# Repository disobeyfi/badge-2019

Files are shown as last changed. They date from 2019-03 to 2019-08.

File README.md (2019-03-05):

# Disobey 2019 badge

Disobey 2019 badge is 3rd electronic badge produced for Disobey. Badge mainly serves as part of the puzzle at the event, while it also offers easy to learn embedded programming platform.

## Intro
Introduction to the badge is well covered here: https://wiki.badge.team/Disobey2019Badge/API

## Programming
Apps for the badge can be written in Micropython and released in https://badge.disobey.fi

The ESP32 firmware development (by badge.team) continues in https://github.com/badgeteam/micropython-esp32

## Features
* 6 RGB leds
* 6 touch buttons
* LCD screen with backlight
* piezoelectric buzzer
* WiFi (2.4 GHz)
* I2C bus
* serial via USB

## Team
* Heikki Juva - Management and hardware
* Kliment - Hardware, drivers and manufacturing
* Renze - Software
* Valtteri Raila - Puzzle
* Gaja - Software
* Otto - Graphics
* Teemu Hakala - Badge assembly workshops

## Thanks
* NotMyNick - The Father of Disobey
* badge.team for creating awesome platform for badges
* Helsinki Hacklab for providing the lab and tools for the workshops

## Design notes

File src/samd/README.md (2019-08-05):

# What is this?
This is the firmware running on the SAMD co-processor found on the Disobey 2019 badge

# How do I compile this firmware?
First install version 1.6.18 of the "Arduino SAMD boards" board support package using the Arduino boards manager.
Then navigate to ~/.arduino15/packages/arduino/hardware/samd and replace the 1.6.18 folder with the folder found in the "arduino-board-support.zip" archive.

Then open "firmware.ino" with the Arduino IDE and click Sketch > Export compiled binary

# How do I flash the binary to my board?
First solder on SW1 and SW2 if you did not do that already.
Then hold SW2 (the SAMD bootloader trigger pin) while pressing shortly on SW1 (the SAMD reset pin).
This will place the SAMD into download mode.

Then execute the following command:

```
sudo dfu-util -D firmware.ino.disobey.bin -R
```

# How do I use it?

The firmware allows for connecting to the serial port of the ESP32 at 115200 baud.

The ESP32 can access the touch buttons, LEDs, speaker and battery voltage readings over I2C.

# The I2C protocol

# More information
[The github repository for the Disobey 2019 badge](https://github.com/disobeyfi/badge-2019)

# License and authors

The firmware in this repository was originally written for Disobey.fi by Kliment and patched up a bit by Renze.

Copyright 2019 badge.team

All code found in the firmware folder in this repository is licensed under the Apache license,
as found below.

Our dependencies remain licensed under their respective original licenses.

This project contains the following differently licensed files:

The Arduino board support files (the arduino-board-support.zip archive)
The SAMD bootloader by Alex Taradov and Peter Lawrence

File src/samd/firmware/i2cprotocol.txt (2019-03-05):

i2c protocol
commands (write):
0x01: set LED (ledid, r,g,b)
    r,g,b=0-0xff
    ledid=0-5, 6=all
0x02: set backlight (value=0-255)
0x03: set buzzer freq (freq (2 bytes, Hz, 0=off), duration (2 bytes, ms, 0=continuous))
0x04: set everything off (backlight, LEDs, buzzer)

state (read):
byte 0: button state 0|U|T0|T1|T2|T3|T4|T5 (U is USB connected status)
byte 1: battery state
reading state resets interrupt

Touch state machine:

IDLE = 0
WAITING
DONE

(internal state: readings, buttonstate, offsets, curindex)

Transitions:
IDLE (check number of iterations) -> DONE, index=-1
DONE (increment index, start conversion) -> (if index<6)->WAITING (if index==6)->IDLE
WAITING (check conversion state) -> (id conversion ready)->DONE (else)->WAITING

LED driver setup:

(internal state: value of each LED for each channel, led index, channel index)

On timer trigger: 
    disable all LEDs, 
    increment channel index, 
    if channel index==3 reset channel index to zero, increment LED index
    if led index==6 reset led index to 0
Enable anode of LED pointed to by LED index (set to high)
Set cathode PWM duty cycle to 255-value[channel]

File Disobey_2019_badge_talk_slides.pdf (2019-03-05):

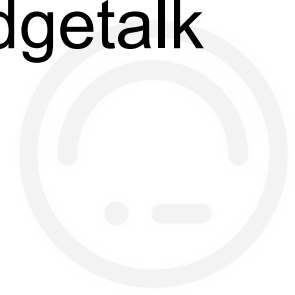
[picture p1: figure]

# Unscheduled badgetalk

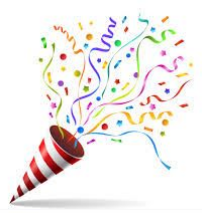
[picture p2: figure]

## Suprise!

## About the badge

- Runs MicroPython
- Connectivity over USB, WiFi and IR
- Has an appstore (badge.disobey.fi)

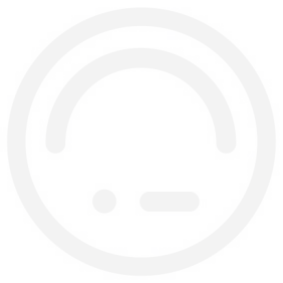
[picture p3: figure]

Features

- 6 touch buttons
- 128x64 LCD screen
- 6 RGB LEDs
- IR transmitter and receiver
- Buzzer
- WiFi
- USB serial connection

## What can you do with it?

- Run the rainbow app
- Enjoy the blank screen
- Drain batteries

## What can you do with it?

- Have it show your (nick)name
- Install apps from the hatchery (badge.disobey.fi)
- Program your own apps in Python

## Features

- 6 touch buttons
- 128x64 LCD screen
- 6 RGB LEDs
- IR transmitter and receiver
- Buzzer
- WiFi
- USB serial connection

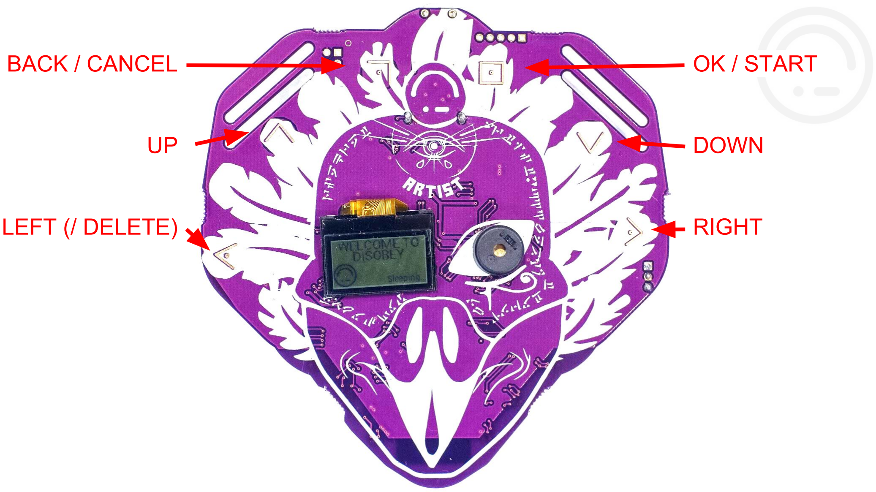
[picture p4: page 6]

OK / START

DOWN

RIGHT

BACK / CANCEL

UP

LEFT (/ DELETE)

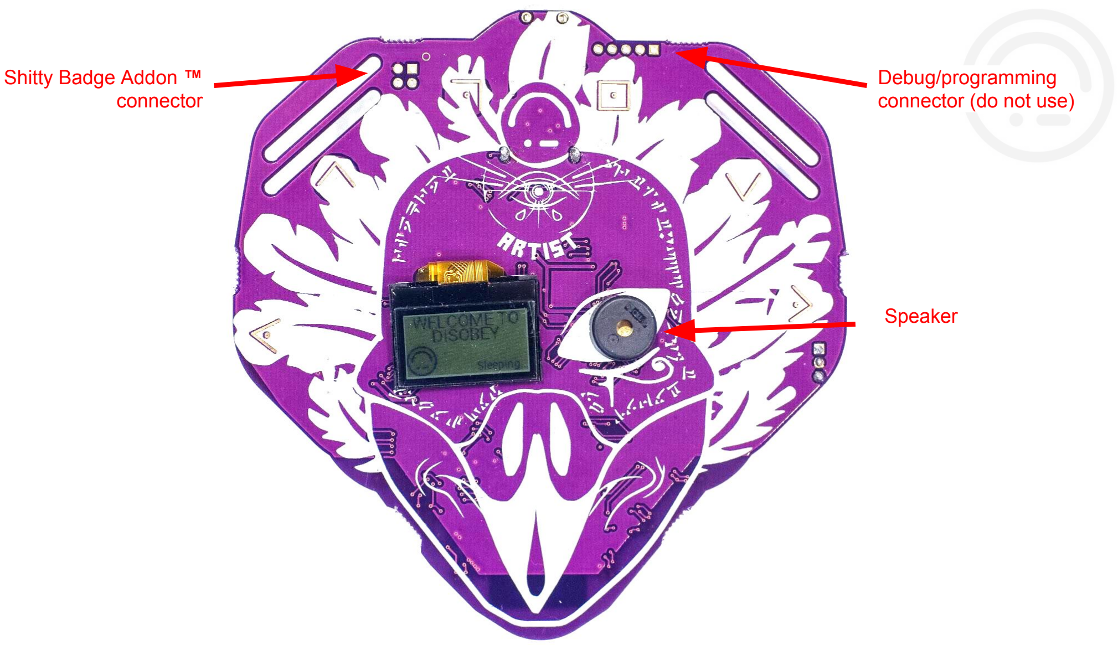
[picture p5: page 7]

Debug/programming
connector (do not use)

Shitty Badge Addon ™
connector

Speaker

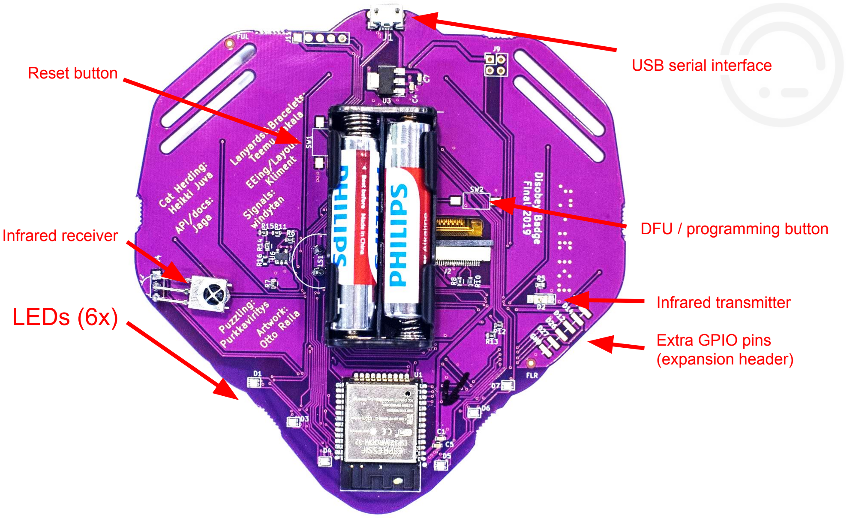
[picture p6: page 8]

Infrared receiver

LEDs (6x)

Reset button

DFU / programming button

Infrared transmitter

Extra GPIO pins
(expansion header)

USB serial interface

# Installing apps

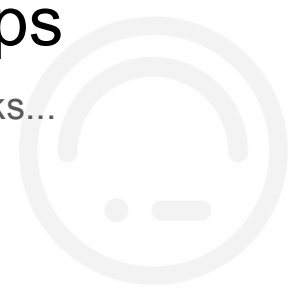
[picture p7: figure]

for when the WiFi works...

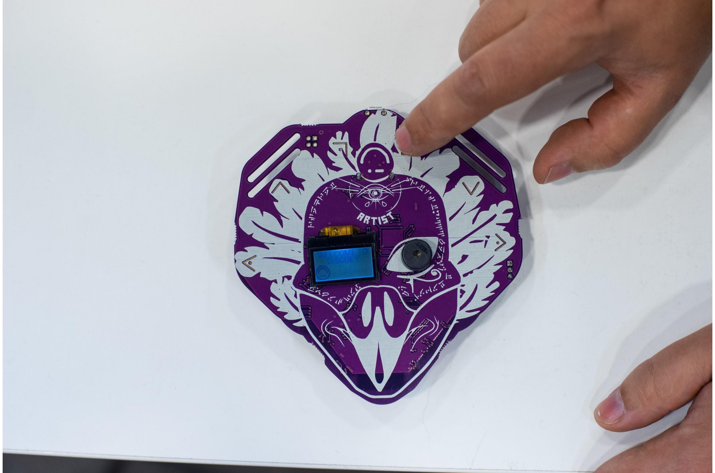
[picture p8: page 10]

## Main menu

- Installed apps
- Installer
- Update apps
- Update firmware
- Home

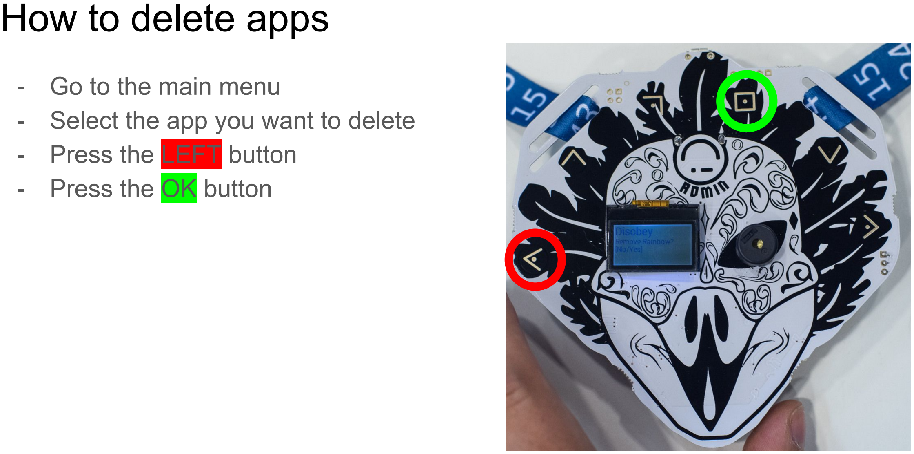
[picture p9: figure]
How to delete apps; - Go to the main menu - Select the app you want to delete - Press the LEFT button - Press the OK button

## Developing apps

## - https://badge.disobey.fi

# - Contains documentation!

- Publish apps written in MicroPython

## Make more apps!

## (More app examples at https://badge.team)

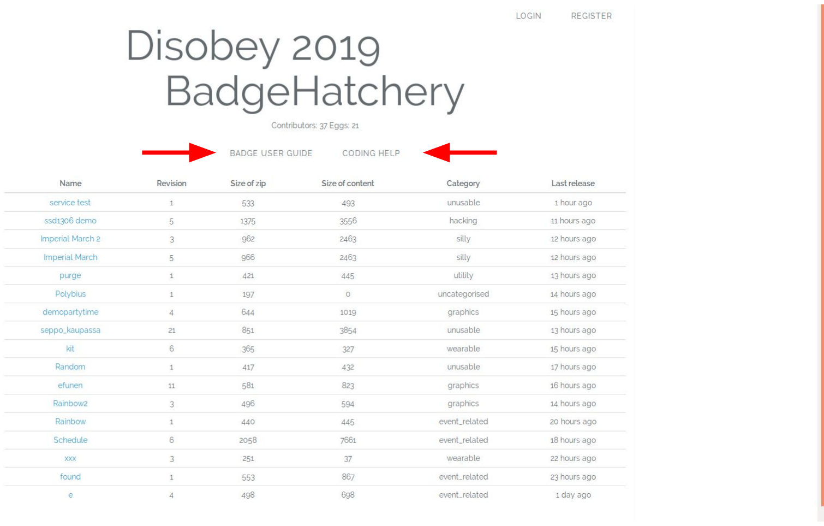
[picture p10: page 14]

# Failure modes

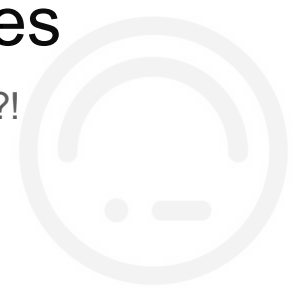
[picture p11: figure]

## Help it doesn’t work?!

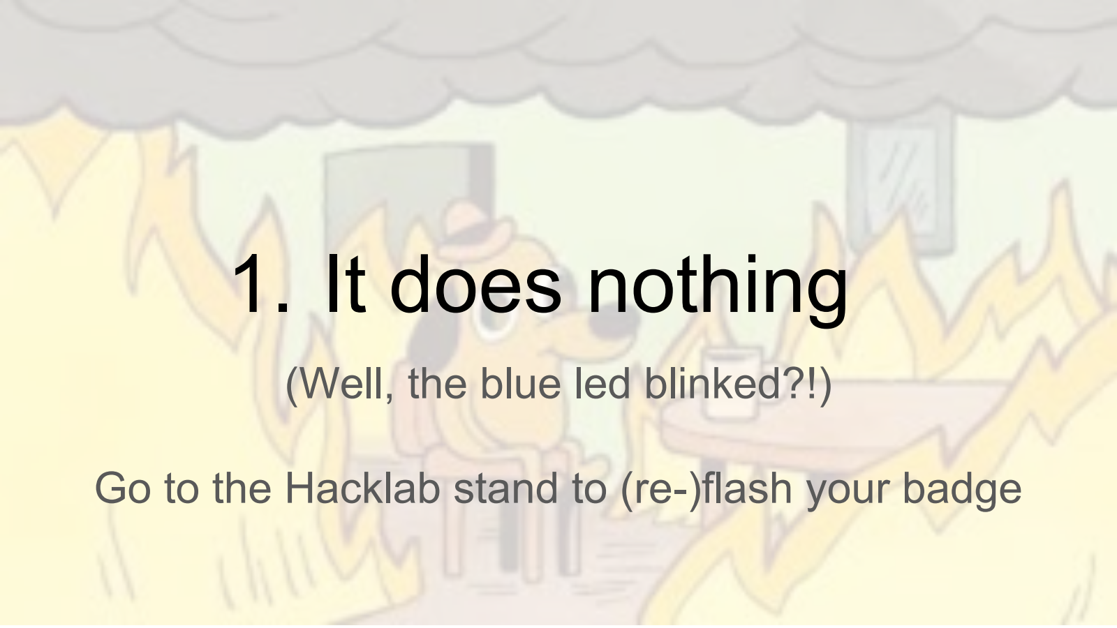
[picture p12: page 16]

# 1. It does nothing

## (Well, the blue led blinked?!)

## Go to the Hacklab stand to (re-)flash your badge

# 2. It keeps loading

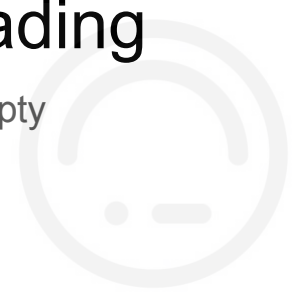
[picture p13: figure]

## Your batteries are empty

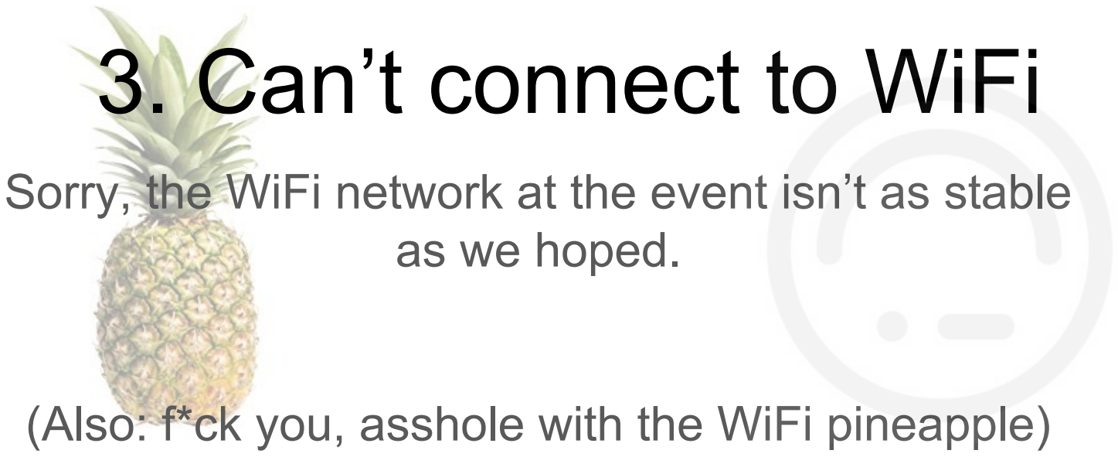
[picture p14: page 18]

# 3. Can’t connect to WiFi

## Sorry, the WiFi network at the event isn’t as stable

as we hoped.

## (Also: f*ck you, asshole with the WiFi pineapple)

# 4. OTA update

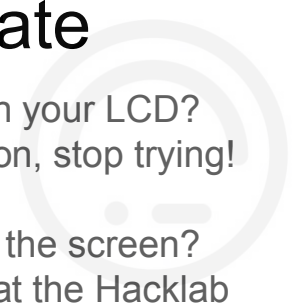
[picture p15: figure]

## Do you see the Disobey logo on your LCD? You’re already on the latest version, stop trying!

## Don’t have the disobey logo on the screen? You can get your badge flashed at the Hacklab

# 5. It’s complicated

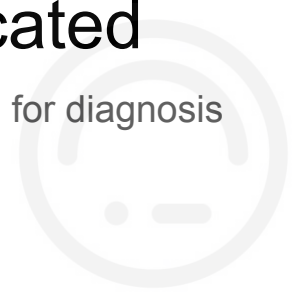
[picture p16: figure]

## Come to us at the Hacklab stand for diagnosis

## USB serial connection

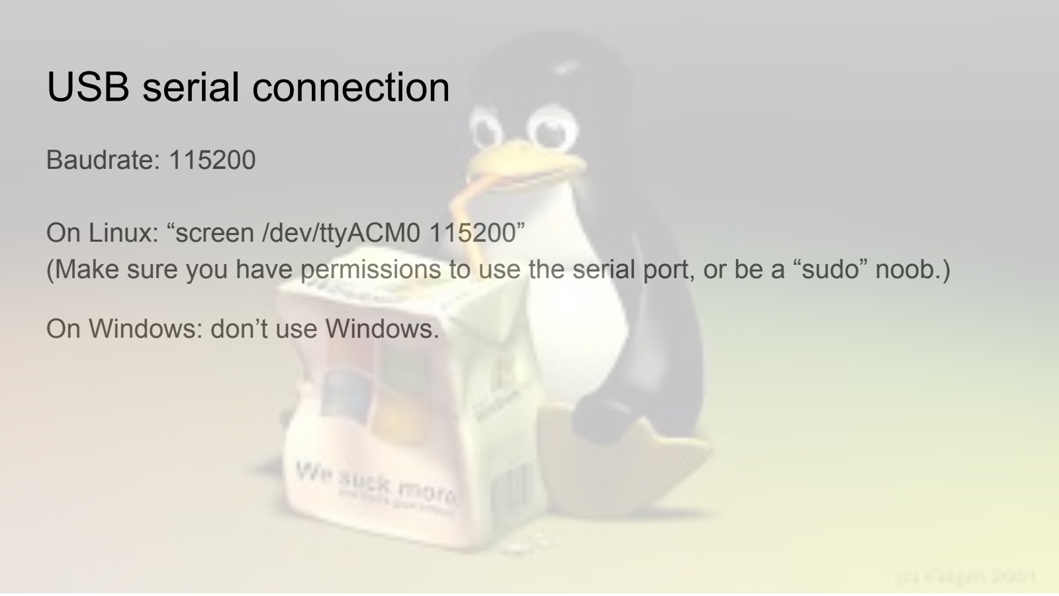
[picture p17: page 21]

Baudrate: 115200

On Linux: “screen /dev/ttyACM0 115200”
(Make sure you have permissions to use the serial port, or be a “sudo” noob.)

On Windows: don’t use Windows.

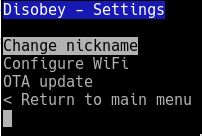
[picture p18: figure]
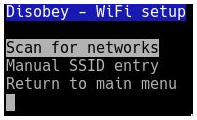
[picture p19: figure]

Want to test/develop applications? Use the Python shell
See the documentation on the MicroPython website.
Hint: ctrl+e enters “paste mode”, then pressing ctrl+d runs the code ctrl+d while not in paste mode is reset/reboot!
ctrl+c to cancel a running command

To access the menu on a sleeping badge: press any button on your badge to wake it up

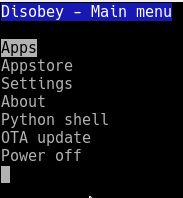
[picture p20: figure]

Useful modules (“import <module>”)

1. | badge | Main gateway to hardware features of the badge badge.led(<led number>, <red 0-255>, <green 0-255>, <blue 0-255>) badge.buzzer(<frequency>, <duration in ms or 0 for endless>) badge.backlight(<0-255>)
2. | ugfx | Graphics and input library ugfx.clear(ugfx.WHITE) ugfx.line(0,0,64,64, ugfx.BLACK) ugfx.string(0,0,"Hello", "PermanentMarker22", ugfx.BLACK) ugfx.flush()
| | def myCallback(pressed): if (pressed): print(“Button pressed”) else: print(“Button released”)
ugfx.input_attach(ugfx.JOY_UP, myCallback) | JOY_UP, JOY_DOWN, JOY_LEFT, JOY_RIGHT, BTN_B, BTN_START

Useful modules (“import <module>”)

1. badge
2. ugfx
3. ir
4. easydraw
5. easywifi
6. …

## > Read the API docs, available on the Hatchery < > https://badge.disobey.fi/firmware/badge_API.txt <

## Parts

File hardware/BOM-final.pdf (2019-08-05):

### Sheet1

LIN | RD | Q Part | MPN | DPN | DN
| 1 U1 | 1 ESP32 mod | ESP-WROOM-32D
| 2 J2 | 1 LCD connector | ER-CON30HB-1
3 U5 | 1 Boost converter 3.3V TSOT-23-6 AAT1217ICA-3.3-T1 | digikey
| 4 L1 | 1 Inductor 0805 | MLZ2012M4R7HT000 | | digikey
| 5 U2 | 1 usb micro qfn48 | ATSAMD21G16B-MUT
| 6 D1 D3 D4 D5 D6 D7 | 6 RGB LED, common anode 0606
| 7 D2 | 1 IR emitter | APTD3216F3C-P22 | | digikey
| 8 U6 | 1 Opamp SOT-23-5 | MCP6001T-I/OT | | digikey
| 9 U3 | 1 LDO 3.3V SOT223 | AZ1117EH-3.3TRG1 | | digikey
| 10 J1 | 1 USB connector | 10118193-0001LF | | digikey
| 11 C3 C6 | 2 100n cap 0603 | 06033C104KAT4A | | digikey
| 12 C1 C2 C4 C5 C7 C8 C9 | 7 10u cap 0603 | GRM188R61A106KE69D | | digikey
| 13 R1 R2 R3 R14 | 4 330R 0603 resistor | RC0603FR-07330RL | | digikey
| 14 R4 R16 | 2 2k 0603 resistor | ERJ-3EKF2001V | | digikey
| 15 R5 | 1 1k 0603 resistor | RMCF0603FT1K00 | | digikey
| 16 R6 R7 R11 R12 R13 R15 | 6 100k 0603 resistor | RMCF0603FT100K | | digikey
| 17 R8 R9 R10 | 3 4.7k 0603 resistor | CRG0603F4K7 | | digikey
| TOTAL | 40

### Page 1

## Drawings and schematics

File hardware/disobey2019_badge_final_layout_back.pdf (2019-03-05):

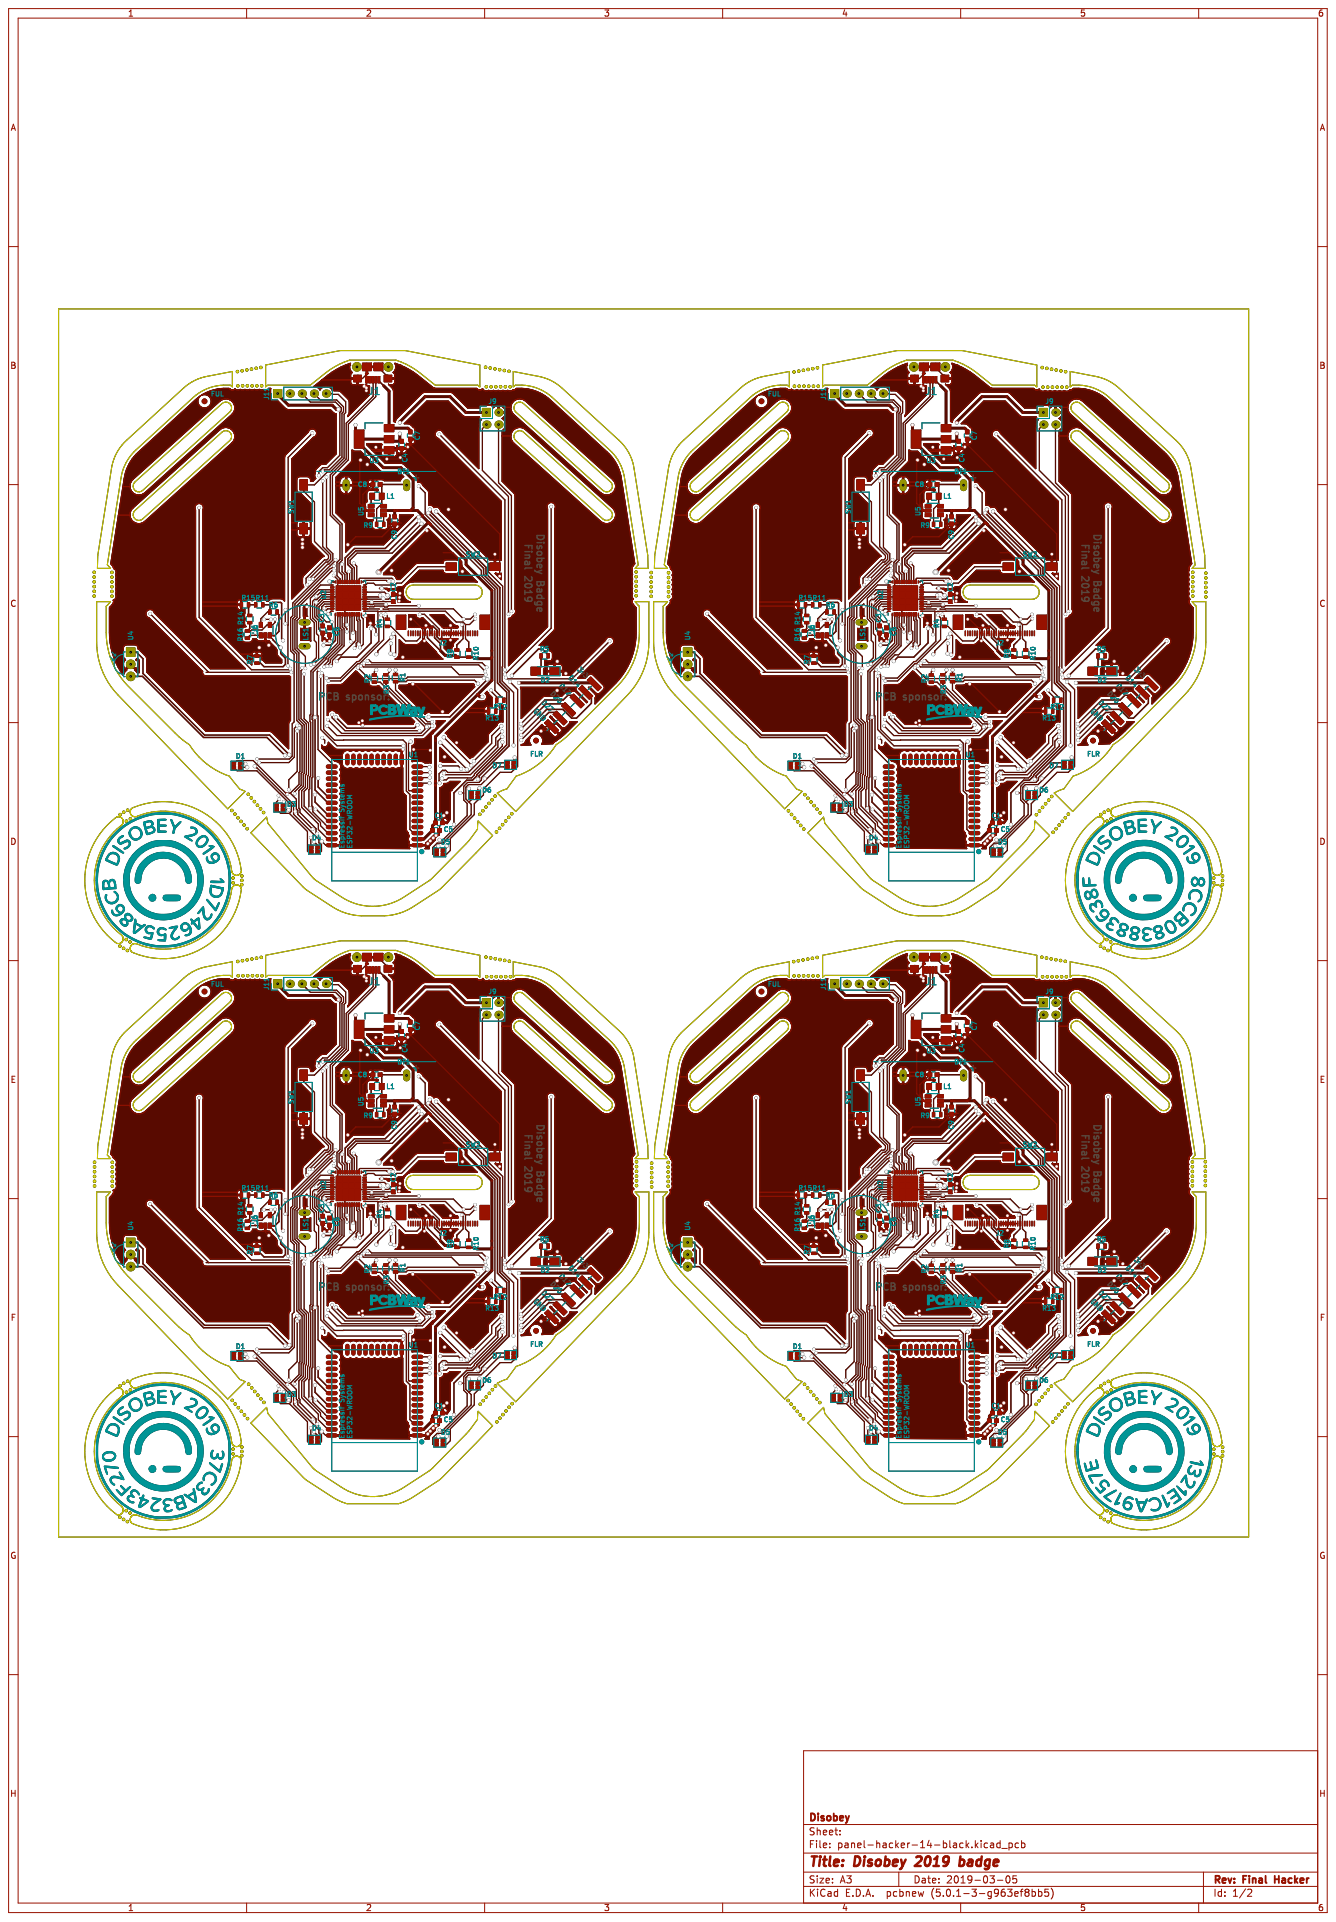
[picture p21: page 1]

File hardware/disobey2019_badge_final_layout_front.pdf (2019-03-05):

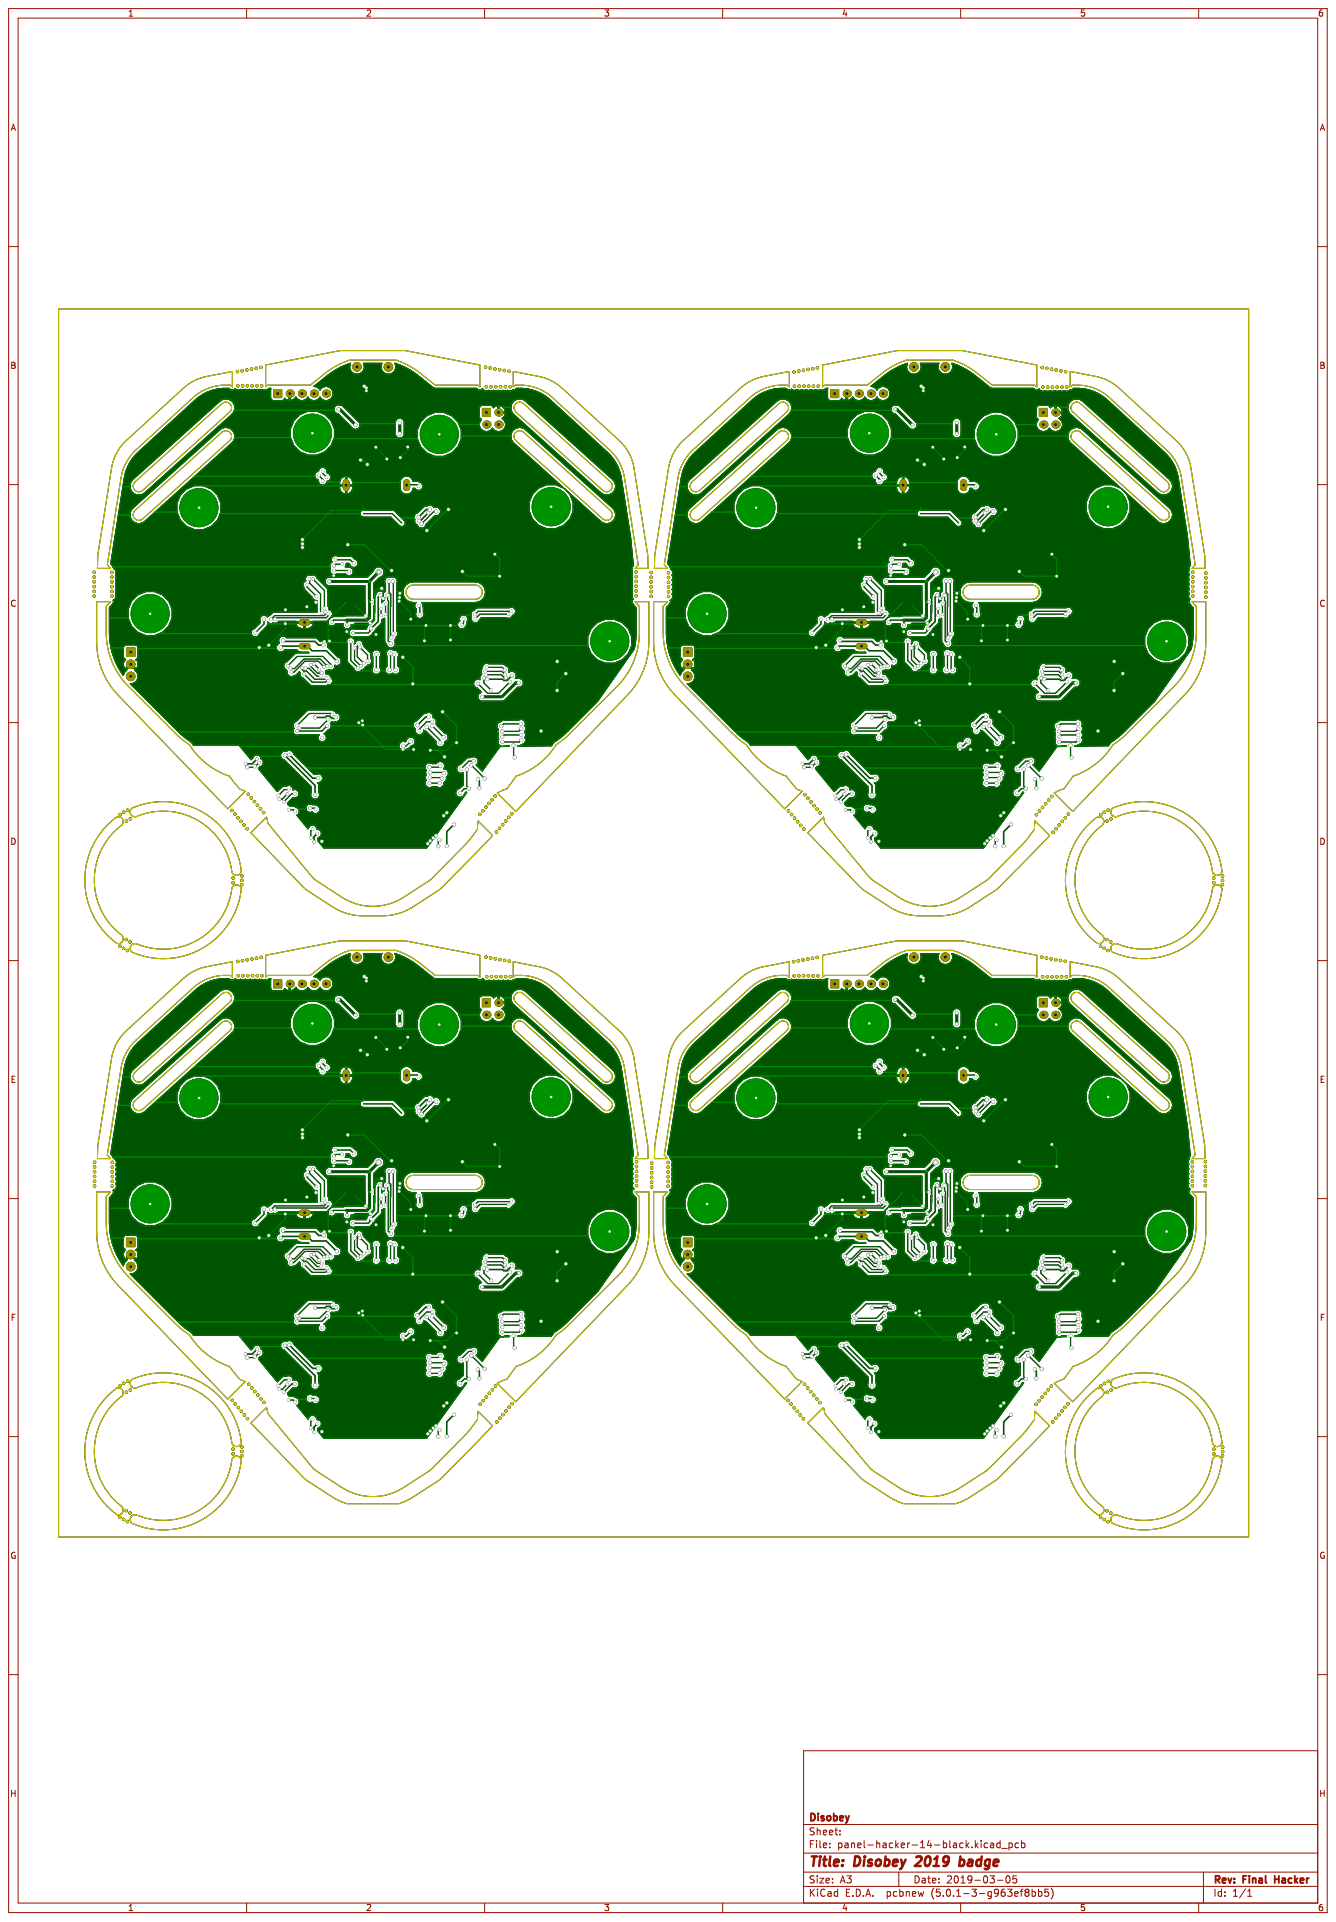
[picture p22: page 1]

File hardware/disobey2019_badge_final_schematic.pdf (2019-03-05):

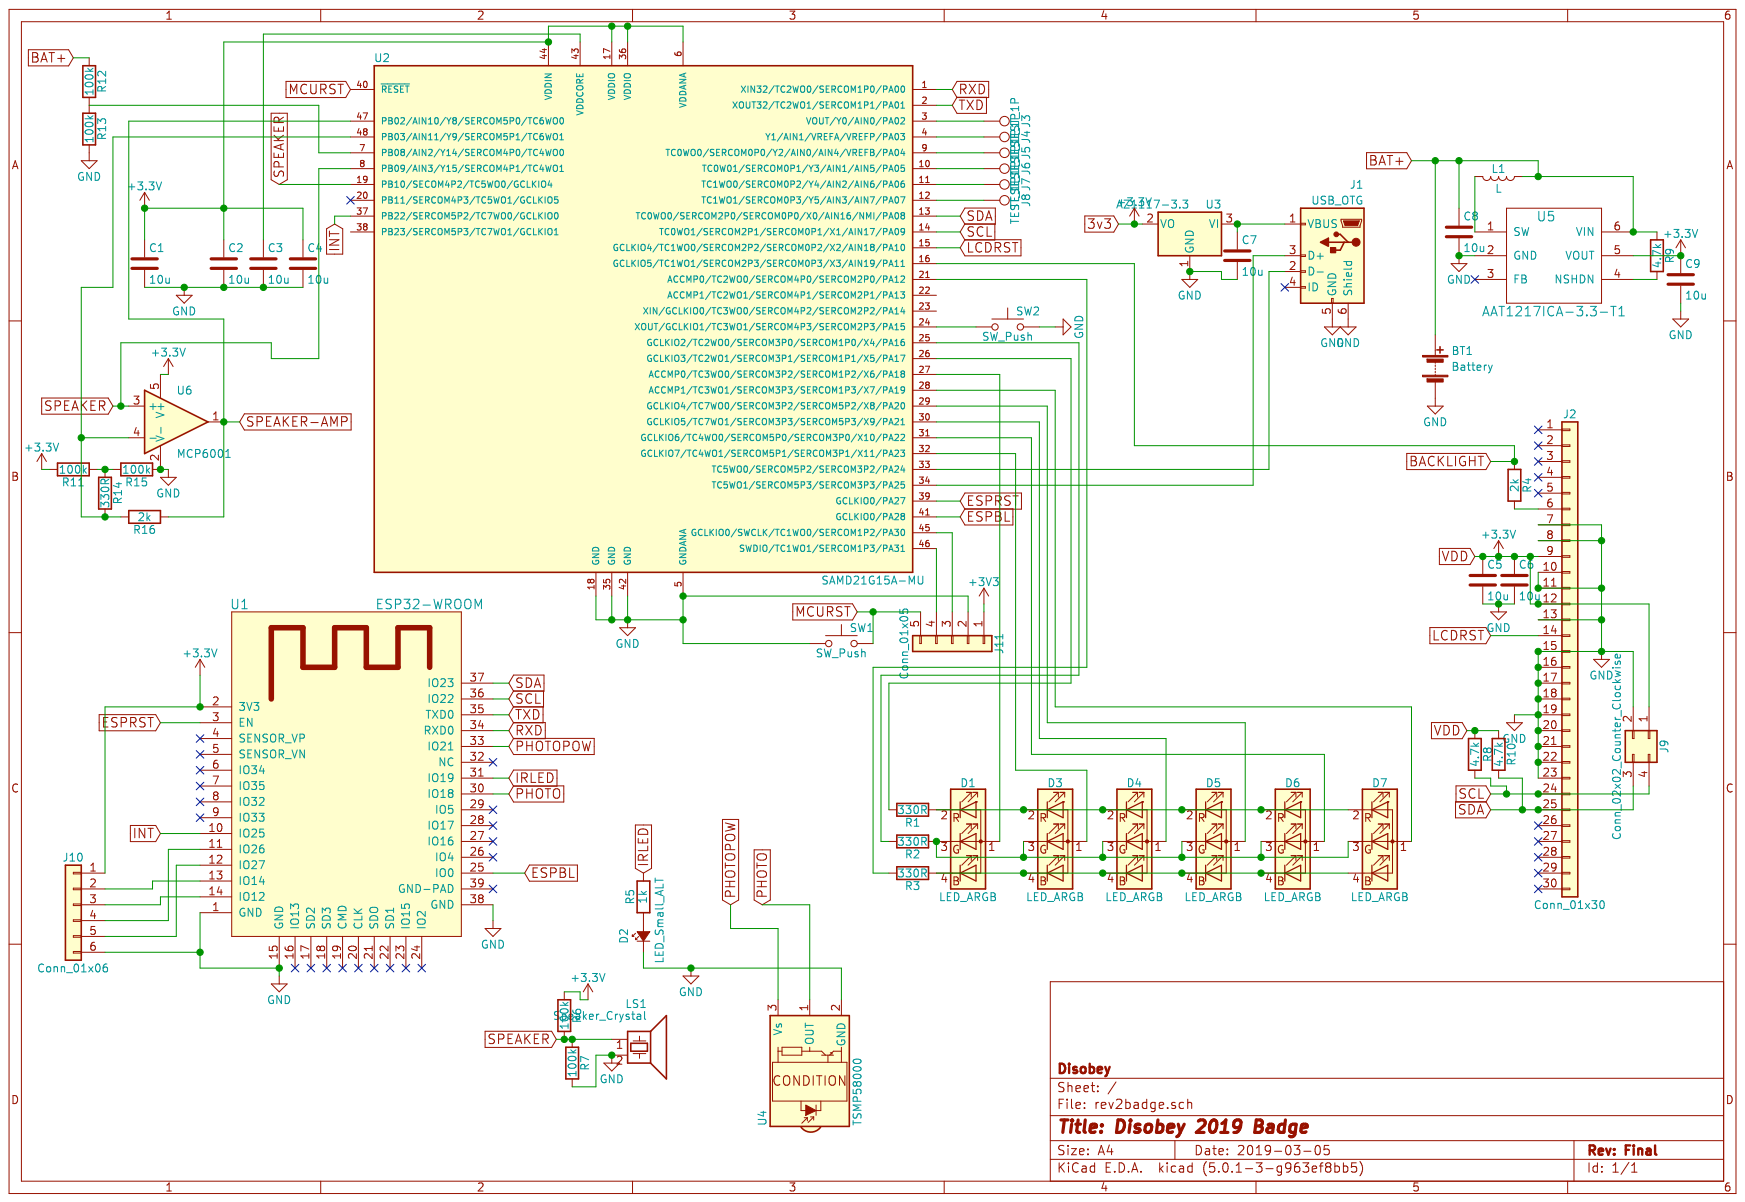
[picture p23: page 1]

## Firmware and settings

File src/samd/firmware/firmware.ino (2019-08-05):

/* Disobey badge 2019 */
#include "hw.h"
#include <Wire.h>
#include <Tone.h>

#define FSM_OFF      0x01 //USB is disconnected
#define FSM_ON       0x02 //USB is connected and either idle or active
#define FSM_SUSPEND  0x04 //L2 suspended
#define FSM_SLEEP    0x08 //L1 sleep
#define FSM_DNRESUME 0x10 //Down stream resume
#define FSM_UPRESUME 0x20 //Up stream resume
#define FSM_RESET    0x40 //USB lines reset


#define NVM_MEMORY ((volatile uint16_t *)0x000000)
#define APP_START 0x400


static inline bool nvmReady(void) {
        return NVMCTRL->INTFLAG.reg & NVMCTRL_INTFLAG_READY;
}

/*__attribute__ ((long_call, section (".ramfunc")))
static void selfdestruct() {
    __disable_irq();
    while (!nvmReady())
        ;
    NVMCTRL->STATUS.reg |= NVMCTRL_STATUS_MASK;
    NVMCTRL->ADDR.reg  = (uintptr_t)&NVM_MEMORY[APP_START / 4];
    NVMCTRL->CTRLA.reg = NVMCTRL_CTRLA_CMD_ER | NVMCTRL_CTRLA_CMDEX_KEY;
    while (!nvmReady())
        ;
    NVIC_SystemReset() ;
    while (true);
}*/

Touchcontrol *t;
LEDcontrol *l;
volatile uint8_t responsebuffer[2]={0};

void setup() {
  //Pin configuration
  pinMode(PIN_BTN,       INPUT_PULLUP);
  pinMode(PIN_ESP_GPIO0, OUTPUT);
  pinMode(PIN_ESP_RESET, OUTPUT);
  pinMode(PIN_LCD_RESET, OUTPUT);
  pinMode(PIN_LCD_BACKL, OUTPUT);
  pinMode(PIN_LED_AR,    OUTPUT);
  pinMode(PIN_LED_AG,    OUTPUT);
  pinMode(PIN_LED_AB,    OUTPUT);
  pinMode(PIN_LED_C1,    OUTPUT);
  pinMode(PIN_LED_C2,    OUTPUT);
  pinMode(PIN_LED_C3,    OUTPUT);
  pinMode(PIN_LED_C4,    OUTPUT);
  pinMode(PIN_LED_C5,    OUTPUT);
  pinMode(PIN_LED_C6,    OUTPUT);
  pinMode(PIN_I2C_INT,   OUTPUT);

  //Initial output values
  digitalWrite(PIN_ESP_GPIO0, HIGH); //Normal ESP32 boot
  digitalWrite(PIN_LCD_RESET, LOW);  //Disable LCD
  digitalWrite(PIN_ESP_RESET, LOW);  //Disable ESP32
  digitalWrite(PIN_I2C_INT,   LOW);  //No I2C interrupt

  //Start the USB-serial port and the UART connected to the ESP32
  Serial1.begin(115200);
  Serial.begin(115200);

  //Small delay to let things settle
  delay(50);

  //Start the ESP32
  digitalWrite(PIN_LCD_RESET,HIGH); //Enable LCD
  digitalWrite(PIN_ESP_RESET,HIGH); //Enable ESP32

  analogReadResolution(8);
  
  responsebuffer[1] = analogRead(PIN_ADC_VBATT); //We do one normal, synced analog read to configure the pin correctly
    
  Wire.begin(0x30);
  Wire.onReceive(receiveEvent); // register event
  Wire.onRequest(requestEvent); // register event
  
  uint32_t mask;
  
  mask = PM_APBAMASK_WDT | PM_APBAMASK_PAC0 | PM_APBAMASK_EIC;
  PM->APBAMASK.reg &= ~mask;

  mask = PM_APBBMASK_PAC1 | PM_APBBMASK_DSU | PM_APBBMASK_DMAC | PM_APBBMASK_NVMCTRL;
  PM->APBBMASK.reg &= ~mask;
    
  mask = PM_APBCMASK_PAC2 | PM_APBCMASK_DAC | PM_APBCMASK_AC | PM_APBCMASK_SERCOM5 | \
         PM_APBCMASK_SERCOM4 | PM_APBCMASK_SERCOM3 | PM_APBCMASK_SERCOM2 | \
         PM_APBCMASK_EVSYS | PM_APBCMASK_I2S;
  PM->APBCMASK.reg &= ~mask;
  
  mask= PM_AHBMASK_DSU | PM_AHBMASK_DMAC;
  PM->AHBMASK.reg &= ~mask;
  
  t=new Touchcontrol(300);
  l=new LEDcontrol(10);
  l->alloff();

  //digitalWrite(PIN_LED_AR, LOW);  //On
  //digitalWrite(PIN_LED_AG, HIGH); //Off
  //digitalWrite(PIN_LED_AB, HIGH); //Off
}


void requestEvent()
{
  digitalWrite(PIN_I2C_INT, HIGH);
  Wire.write((char *)responsebuffer,2); // respond with message of 2 bytes
}

void receiveEvent(int howMany)
{
  if (Wire.available()) {
    int command = Wire.read();
    switch(command) {
      case 0x01: {
        uint8_t id = Wire.read();
        uint8_t r  = Wire.read();
        uint8_t g  = Wire.read();
        uint8_t b  = Wire.read();
        l->setled(id, r, g, b);
        break;
      }
      case 0x02: {
        l->setbl(Wire.read());
        break;
      }
      case 0x03: {
        uint8_t  freq_h = Wire.read();
        uint8_t  freq_l = Wire.read();
        uint8_t  dur_h  = Wire.read();
        uint8_t  dur_l  = Wire.read();
        uint16_t freq   = (freq_h<<8)|(freq_l);
        uint16_t dur    = (dur_h<<8)|(dur_l);
        l->setbuzz(freq,dur);
        break;
      }
      case 0x04:
        l->alloff();
        break;
    }
  }
}

uint8_t vbatt_adc_status = 0xFF; //Go to "default"
unsigned long previousVbattMillis = 0;
const unsigned long vbattInterval = 1000;
inline void update_vbatt_status()
{
  //responsebuffer[1] = analogRead(PIN_ADC_VBATT); //The code below replaces this function
  switch(vbatt_adc_status) {
    case 0:
      if (!ADC->STATUS.bit.SYNCBUSY) {
        ADC->CTRLA.bit.ENABLE = 1;
        vbatt_adc_status = 1;
      }
      break;
    case 1: //Waiting for sync
      if (!ADC->STATUS.bit.SYNCBUSY) {
        ADC->INPUTCTRL.bit.MUXPOS = g_APinDescription[PIN_ADC_VBATT].ulADCChannelNumber;
        vbatt_adc_status = 2;
      }
      break;
    case 2:
      if (!ADC->STATUS.bit.SYNCBUSY) {
        ADC->CTRLA.bit.ENABLE = 0x01;
        vbatt_adc_status = 3;
      }
      break;
    case 3:
      if (!ADC->STATUS.bit.SYNCBUSY) {
        ADC->SWTRIG.bit.START = 1;
        ADC->INTFLAG.reg = ADC_INTFLAG_RESRDY;
        vbatt_adc_status = 4;
      }
      break;
    case 4:
      if (!ADC->STATUS.bit.SYNCBUSY) {
        ADC->SWTRIG.bit.START = 1;
        vbatt_adc_status = 5;
      }
      break;
    case 5:
      if (ADC->INTFLAG.bit.RESRDY) {
        //Serial.println("ADC value "+String(ADC->RESULT.reg));
        responsebuffer[1] = ADC->RESULT.reg;
        vbatt_adc_status = 6;
      }
      break;
    case 6:
      if (!ADC->STATUS.bit.SYNCBUSY) {
        ADC->CTRLA.bit.ENABLE = 0x00;
        vbatt_adc_status = 7;
      }
      break;
    default:
      unsigned long currentVbattMillis = millis();
      if (currentVbattMillis - previousVbattMillis >= vbattInterval) {
        previousVbattMillis = currentVbattMillis;
        //Serial.println("ACTUAL FUNC "+String(analogRead(PIN_ADC_VBATT)));
        vbatt_adc_status = 0; //Start!
      }
  }
}

unsigned long previousResetMillis = 0;
const unsigned long resetInterval = 100;
extern uint8_t getLineState();
uint8_t prevLineState = 0xFF;
int resetTrigger = -1;
inline void update_reset_status()
{
  unsigned long currentResetMillis = millis();
  if (currentResetMillis - previousResetMillis >= resetInterval) {
    previousResetMillis = currentResetMillis;
    uint8_t lineState = getLineState();
    if (lineState!=prevLineState) {
        if (lineState == 0x02) resetTrigger = 20;
        if (lineState == 0x01 && resetTrigger > 0) {
          resetTrigger = 0;
          //To bootloader mode
          digitalWrite(PIN_ESP_GPIO0,LOW);
          digitalWrite(PIN_ESP_RESET,LOW);
          delay(100);
          digitalWrite(PIN_ESP_RESET,HIGH);
          delay(100);
          digitalWrite(PIN_ESP_GPIO0,HIGH);
        }
      prevLineState = lineState;
    }
    if (resetTrigger > 0) {
      if (resetTrigger == 1) {
        //To normal mode
        digitalWrite(PIN_ESP_GPIO0,HIGH);
        digitalWrite(PIN_ESP_RESET,LOW);
        delay(100);
        digitalWrite(PIN_ESP_RESET,HIGH);
      }
      resetTrigger--;
    }
  }
}

inline void update_touch_status()
{
  for (int i=0;i<6;i++) {
    if(t->buttons[i]){
      responsebuffer[0]|=(1<<i);
    }else{
      responsebuffer[0]&=~(1<<i);
    }
  }
}

inline void update_usb_status()
{
  switch(USB->DEVICE.FSMSTATUS.reg)
  {
    case FSM_OFF:
      responsebuffer[0]|=(1<<6);
      break;
    default: //USB is in any other state than OFF
      responsebuffer[0]&=~(1<<6);
  }
}

inline void update_serial()
{
  while (Serial.available()) {
    Serial1.write(Serial.read());
  }
  
  while (Serial1.available()) {
    Serial.write(Serial1.read());
  }
}

void loop()
{
  update_serial();
  
  //responsebuffer[0] ^= (-digitalRead(PIN_BTN) ^ responsebuffer[0]) & (1UL << 7);
  if (!digitalRead(PIN_BTN)) {
      digitalWrite(PIN_ESP_RESET,LOW);
      delay(100);
      digitalWrite(PIN_ESP_RESET,HIGH);
  }
  
  update_vbatt_status();
  update_serial();
  update_reset_status();
  update_serial();
  update_usb_status();
  update_touch_status();
  t->tick();
}

    

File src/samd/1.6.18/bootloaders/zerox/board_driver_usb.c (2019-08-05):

/*
  Copyright (c) 2015 Arduino LLC.  All right reserved.
  Copyright (c) 2015 Atmel Corporation/Thibaut VIARD.  All right reserved.

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
  You should have received a copy of the GNU Lesser General Public
  License along with this library; if not, write to the Free Software
  Foundation, Inc., 51 Franklin St, Fifth Floor, Boston, MA  02110-1301  USA
*/

#include <string.h>
#include "board_driver_usb.h"
#include "sam_ba_usb.h"
#include "sam_ba_cdc.h"

#define NVM_USB_PAD_TRANSN_POS            (45)
#define NVM_USB_PAD_TRANSN_SIZE           (5)
#define NVM_USB_PAD_TRANSP_POS            (50)
#define NVM_USB_PAD_TRANSP_SIZE           (5)
#define NVM_USB_PAD_TRIM_POS              (55)
#define NVM_USB_PAD_TRIM_SIZE             (3)

__attribute__((__aligned__(4))) UsbDeviceDescriptor usb_endpoint_table[MAX_EP]; // Initialized to zero in USB_Init
__attribute__((__aligned__(4))) uint8_t udd_ep_out_cache_buffer[2][64]; //1 for CTRL, 1 for BULK
__attribute__((__aligned__(4))) uint8_t udd_ep_in_cache_buffer[2][64]; //1 for CTRL, 1 for BULK

static volatile bool read_job = false;

/*----------------------------------------------------------------------------
 * \brief
 */
P_USB_CDC USB_Open(P_USB_CDC pCdc, Usb *pUsb)
{
  pCdc->pUsb = pUsb;
  pCdc->currentConfiguration = 0;
  pCdc->currentConnection    = 0;
  pCdc->IsConfigured = USB_IsConfigured;
//  pCdc->Write        = USB_Write;
//  pCdc->Read         = USB_Read;

  pCdc->pUsb->HOST.CTRLA.bit.ENABLE = true;

  return pCdc;
}

/*----------------------------------------------------------------------------
 * \brief Initializes USB
 */
void USB_Init(void)
{
  uint32_t pad_transn, pad_transp, pad_trim;

  /* Enable USB clock */
  PM->APBBMASK.reg |= PM_APBBMASK_USB;

  /* Set up the USB DP/DN pins */
  PORT->Group[0].PINCFG[PIN_PA24G_USB_DM].bit.PMUXEN = 1;
  PORT->Group[0].PMUX[PIN_PA24G_USB_DM/2].reg &= ~(0xF << (4 * (PIN_PA24G_USB_DM & 0x01u)));
  PORT->Group[0].PMUX[PIN_PA24G_USB_DM/2].reg |= MUX_PA24G_USB_DM << (4 * (PIN_PA24G_USB_DM & 0x01u));
  PORT->Group[0].PINCFG[PIN_PA25G_USB_DP].bit.PMUXEN = 1;
  PORT->Group[0].PMUX[PIN_PA25G_USB_DP/2].reg &= ~(0xF << (4 * (PIN_PA25G_USB_DP & 0x01u)));
  PORT->Group[0].PMUX[PIN_PA25G_USB_DP/2].reg |= MUX_PA25G_USB_DP << (4 * (PIN_PA25G_USB_DP & 0x01u));

  /* ----------------------------------------------------------------------------------------------
   * Put Generic Clock Generator 0 as source for Generic Clock Multiplexer 6 (USB reference)
   */
  GCLK->CLKCTRL.reg = GCLK_CLKCTRL_ID( 6 ) | // Generic Clock Multiplexer 6
              GCLK_CLKCTRL_GEN_GCLK1 | // Generic Clock Generator 0 is source
              GCLK_CLKCTRL_CLKEN ;

  while ( GCLK->STATUS.reg & GCLK_STATUS_SYNCBUSY )
  {
    /* Wait for synchronization */
  }

  /* Reset */
  USB->DEVICE.CTRLA.bit.SWRST = 1;
  while (USB->DEVICE.SYNCBUSY.bit.SWRST)
  {
    /* Sync wait */
  }

  /* Load Pad Calibration */
  pad_transn =( *((uint32_t *)(NVMCTRL_OTP4)
      + (NVM_USB_PAD_TRANSN_POS / 32))
    >> (NVM_USB_PAD_TRANSN_POS % 32))
    & ((1 << NVM_USB_PAD_TRANSN_SIZE) - 1);

  if (pad_transn == 0x1F)
  {
    pad_transn = 5;
  }

  USB->HOST.PADCAL.bit.TRANSN = pad_transn;

  pad_transp =( *((uint32_t *)(NVMCTRL_OTP4)
      + (NVM_USB_PAD_TRANSP_POS / 32))
      >> (NVM_USB_PAD_TRANSP_POS % 32))
      & ((1 << NVM_USB_PAD_TRANSP_SIZE) - 1);

  if (pad_transp == 0x1F)
  {
    pad_transp = 29;
  }

  USB->HOST.PADCAL.bit.TRANSP = pad_transp;
  pad_trim =( *((uint32_t *)(NVMCTRL_OTP4)
      + (NVM_USB_PAD_TRIM_POS / 32))
      >> (NVM_USB_PAD_TRIM_POS % 32))
      & ((1 << NVM_USB_PAD_TRIM_SIZE) - 1);

  if (pad_trim == 0x7)
  {
    pad_trim = 3;
  }

  USB->HOST.PADCAL.bit.TRIM = pad_trim;

  /* Set the configuration */
  /* Set mode to Device mode */
  USB->HOST.CTRLA.bit.MODE = 0;
  /* Enable Run in Standby */
  USB->HOST.CTRLA.bit.RUNSTDBY = true;
  /* Set the descriptor address */
  USB->HOST.DESCADD.reg = (uint32_t)(&usb_endpoint_table[0]);
  /* Set speed configuration to Full speed */
  USB->DEVICE.CTRLB.bit.SPDCONF = USB_DEVICE_CTRLB_SPDCONF_FS_Val;
  /* Attach to the USB host */
  USB->DEVICE.CTRLB.reg &= ~USB_DEVICE_CTRLB_DETACH;

  /* Initialize endpoint table RAM location to a known value 0 */
  memset((uint8_t *)(&usb_endpoint_table[0]), 0, sizeof(usb_endpoint_table));
}
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

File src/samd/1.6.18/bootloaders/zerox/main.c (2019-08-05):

/*
  Copyright (c) 2015 Arduino LLC.  All right reserved.
  Copyright (c) 2015 Atmel Corporation/Thibaut VIARD.  All right reserved.

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
  You should have received a copy of the GNU Lesser General Public
  License along with this library; if not, write to the Free Software
  Foundation, Inc., 51 Franklin St, Fifth Floor, Boston, MA  02110-1301  USA
*/

#include <stdio.h>
#include <sam.h>
#include "sam_ba_monitor.h"
#include "sam_ba_serial.h"
#include "board_definitions.h"
#include "board_driver_led.h"
#include "board_driver_i2c.h"
#include "sam_ba_usb.h"
#include "sam_ba_cdc.h"

extern uint32_t __sketch_vectors_ptr; // Exported value from linker script
extern void board_init(void);

volatile uint32_t* pulSketch_Start_Address;

uint32_t rxsize=0;
uint8_t rxbuf[65];
uint8_t txbuf[65];

static void jump_to_application(void) {

  /* Rebase the Stack Pointer */
  __set_MSP( (uint32_t)(__sketch_vectors_ptr) );

  /* Rebase the vector table base address */
  SCB->VTOR = ((uint32_t)(&__sketch_vectors_ptr) & SCB_VTOR_TBLOFF_Msk);

  /* Jump to application Reset Handler in the application */
  asm("bx %0"::"r"(*pulSketch_Start_Address));
}

static volatile bool main_b_cdc_enable = false;

#ifdef CONFIGURE_PMIC
static volatile bool jump_to_app = false;
#endif

/**
 * \brief Check the application startup condition
 *
 */
static void check_start_application(void)
{
//  LED_init();
//  LED_off();

  /*
   * Test sketch stack pointer @ &__sketch_vectors_ptr
   * Stay in SAM-BA if value @ (&__sketch_vectors_ptr) == 0xFFFFFFFF (Erased flash cell value)
   */
  if (__sketch_vectors_ptr == 0xFFFFFFFF)
  {
    /* Stay in bootloader */
    return;
  }

  /*
   * Load the sketch Reset Handler address
   * __sketch_vectors_ptr is exported from linker script and point on first 32b word of sketch vector table
   * First 32b word is sketch stack
   * Second 32b word is sketch entry point: Reset_Handler()
   */
  pulSketch_Start_Address = &__sketch_vectors_ptr ;
  pulSketch_Start_Address++ ;

  /*
   * Test vector table address of sketch @ &__sketch_vectors_ptr
   * Stay in SAM-BA if this function is not aligned enough, ie not valid
   */
  if ( ((uint32_t)(&__sketch_vectors_ptr) & ~SCB_VTOR_TBLOFF_Msk) != 0x00)
  {
    /* Stay in bootloader */
    return;
  }

#if defined(BOOT_DOUBLE_TAP_ADDRESS)
  #define DOUBLE_TAP_MAGIC 0x07738135
  if (PM->RCAUSE.bit.POR)
  {
    /* On power-on initialize double-tap */
    BOOT_DOUBLE_TAP_DATA = 0;
  }
  else
  {
    if (BOOT_DOUBLE_TAP_DATA == DOUBLE_TAP_MAGIC)
    {
      /* Second tap, stay in bootloader */
      BOOT_DOUBLE_TAP_DATA = 0;
      return;
    }

    /* First tap */
    BOOT_DOUBLE_TAP_DATA = DOUBLE_TAP_MAGIC;

    /* Wait 0.5sec to see if the user tap reset again.
     * The loop value is based on SAMD21 default 1MHz clock @ reset.
     */
    for (uint32_t i=0; i<125000; i++) /* 500ms */
      /* force compiler to not optimize this... */
      __asm__ __volatile__("");

    /* Timeout happened, continue boot... */
    BOOT_DOUBLE_TAP_DATA = 0;
  }
#endif

/*
#if defined(BOOT_LOAD_PIN)
  volatile PortGroup *boot_port = (volatile PortGroup *)(&(PORT->Group[BOOT_LOAD_PIN / 32]));
  volatile bool boot_en;

  // Enable the input mode in Boot GPIO Pin
  boot_port->DIRCLR.reg = BOOT_PIN_MASK;
  boot_port->PINCFG[BOOT_LOAD_PIN & 0x1F].reg = PORT_PINCFG_INEN | PORT_PINCFG_PULLEN;
  boot_port->OUTSET.reg = BOOT_PIN_MASK;
  // Read the BOOT_LOAD_PIN status
  boot_en = (boot_port->IN.reg) & BOOT_PIN_MASK;

  // Check the bootloader enable condition
  if (!boot_en)
  {
    // Stay in bootloader
    return;
  }
#endif
*/

//  LED_on();
#ifdef CONFIGURE_PMIC
  jump_to_app = true;
#else
  jump_to_application();
#endif

}

#if DEBUG_ENABLE
#	define DEBUG_PIN_HIGH 	port_pin_set_output_level(BOOT_LED, 1)
#	define DEBUG_PIN_LOW 	port_pin_set_output_level(BOOT_LED, 0)
#else
#	define DEBUG_PIN_HIGH 	do{}while(0)
#	define DEBUG_PIN_LOW 	do{}while(0)
#endif


void testinit(){
    
	/* Configure flash wait states */
	NVMCTRL->CTRLB.bit.RWS = 1;

	/* Set OSC8M prescalar to divide by 1 */
	SYSCTRL->OSC8M.bit.PRESC = 0;

	/* Configure OSC8M as source for GCLK_GEN0 */
	GCLK_GENCTRL_Type genctrl={0};
	uint32_t temp_genctrl;
	GCLK->GENCTRL.bit.ID = 0; /* GENERATOR_ID - GCLK_GEN_0 */
	while(GCLK->STATUS.reg & GCLK_STATUS_SYNCBUSY);
	temp_genctrl = GCLK->GENCTRL.reg;
	genctrl.bit.SRC = GCLK_GENCTRL_SRC_OSC8M_Val;
	genctrl.bit.GENEN = true;
	genctrl.bit.RUNSTDBY = false;
	GCLK->GENCTRL.reg = (genctrl.reg | temp_genctrl);
	while(GCLK->STATUS.reg & GCLK_STATUS_SYNCBUSY);

	SYSCTRL_DFLLCTRL_Type dfllctrl_conf = {0};
	SYSCTRL_DFLLVAL_Type dfllval_conf = {0};
	uint32_t coarse =( *((uint32_t *)(NVMCTRL_OTP4)
                    + (NVM_SW_CALIB_DFLL48M_COARSE_VAL / 32))
                    >> (NVM_SW_CALIB_DFLL48M_COARSE_VAL % 32))
                    & ((1 << 6) - 1);
	if (coarse == 0x3f) {
		coarse = 0x1f;
	}
	uint32_t fine =( *((uint32_t *)(NVMCTRL_OTP4)
                  + (NVM_SW_CALIB_DFLL48M_FINE_VAL / 32))
                  >> (NVM_SW_CALIB_DFLL48M_FINE_VAL % 32))
                  & ((1 << 10) - 1);
	if (fine == 0x3ff) {
		fine = 0x1ff;
	}
	dfllval_conf.bit.COARSE  = coarse;
	dfllval_conf.bit.FINE    = fine;
	dfllctrl_conf.bit.USBCRM = true;
	dfllctrl_conf.bit.BPLCKC = false;
	dfllctrl_conf.bit.QLDIS  = false;
	dfllctrl_conf.bit.CCDIS  = true;
	dfllctrl_conf.bit.ENABLE = true;

	SYSCTRL->DFLLCTRL.bit.ONDEMAND = false;
	while (!(SYSCTRL->PCLKSR.reg & SYSCTRL_PCLKSR_DFLLRDY));
	SYSCTRL->DFLLMUL.reg = 48000;
	SYSCTRL->DFLLVAL.reg = dfllval_conf.reg;
	SYSCTRL->DFLLCTRL.reg = dfllctrl_conf.reg;

	GCLK_CLKCTRL_Type clkctrl={0};
	uint16_t temp;
	GCLK->CLKCTRL.bit.ID = 0; /* GCLK_ID - DFLL48M Reference */
	temp = GCLK->CLKCTRL.reg;
	clkctrl.bit.CLKEN = true;
	clkctrl.bit.WRTLOCK = false;
	clkctrl.bit.GEN = GCLK_CLKCTRL_GEN_GCLK0_Val;
	GCLK->CLKCTRL.reg = (clkctrl.reg | temp);

	/* Configure DFLL48M as source for GCLK_GEN1 */
	GCLK->GENCTRL.bit.ID = 1; /* GENERATOR_ID - GCLK_GEN_1 */
	while(GCLK->STATUS.reg & GCLK_STATUS_SYNCBUSY);
	temp_genctrl = GCLK->GENCTRL.reg;
	genctrl.bit.SRC = GCLK_GENCTRL_SRC_DFLL48M_Val;
	genctrl.bit.GENEN = true;
	genctrl.bit.RUNSTDBY = false;
	GCLK->GENCTRL.reg = (genctrl.reg | temp_genctrl);
	while(GCLK->STATUS.reg & GCLK_STATUS_SYNCBUSY);




}
#define GPIO_ON(pin) (PORT->Group[0].OUTSET.reg = (1<<(pin)))
#define GPIO_OFF(pin) (PORT->Group[0].OUTCLR.reg = (1<<(pin)))


void init_GPIO(void){
    //pins PA12-13 and PA16-23 and PA27-28 (LEDS, ESP32 control pins)
  PORT->Group[0].DIRSET.reg = (1<<12)|(1<<13)|(1<<16)|(1<<17)|(1<<18)|
    (1<<19)|(1<<20)|(1<<21)|(1<<22)|(1<<23)|(1<<27)|(1<<28);
    
    GPIO_OFF(27);
    GPIO_OFF(28);
    
    
    GPIO_ON(12);
    GPIO_ON(16);
    GPIO_OFF(17);
    
    GPIO_OFF(18);
    GPIO_OFF(19);
    GPIO_OFF(20);
    GPIO_OFF(21);
    GPIO_OFF(22);
    GPIO_ON(23);
    
    
    
}
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

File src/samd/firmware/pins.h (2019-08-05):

#ifndef _PINS_H_
#define _PINS_H_

#define PIN_BTN       23
#define PIN_ESP_GPIO0 11
#define PIN_ESP_RESET 12
#define PIN_LCD_RESET 15
#define PIN_LCD_BACKL 16
#define PIN_LED_AR     8
#define PIN_LED_AG     9
#define PIN_LED_AB    10
#define PIN_LED_C1     7
#define PIN_LED_C2     4
#define PIN_LED_C3     6
#define PIN_LED_C4     5
#define PIN_LED_C5     3
#define PIN_LED_C6     2
#define PIN_I2C_INT   20
#define PIN_ADC_VBATT A2
#define PIN_TOUCH_1   29
#define PIN_TOUCH_2   30
#define PIN_TOUCH_3   31
#define PIN_TOUCH_4   28
#define PIN_TOUCH_5   27
#define PIN_TOUCH_6   26

const int touch_pins[6] = {
  PIN_TOUCH_1,
  PIN_TOUCH_2,
  PIN_TOUCH_3,
  PIN_TOUCH_4,
  PIN_TOUCH_5,
  PIN_TOUCH_6
};

const int led_pins[6] = {
  PIN_LED_C1,
  PIN_LED_C2,
  PIN_LED_C3,
  PIN_LED_C4,
  PIN_LED_C5,
  PIN_LED_C6
};

const int rgb_pins[3] = {
  PIN_LED_AR,
  PIN_LED_AG,
  PIN_LED_AB
};

#endif

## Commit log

2019-06-05 Added submodule of esp32 source from badge.team
2019-08-05 Linked to updated SAMD firmware
    [arduino_zero.cfg]
2019-08-05 Updated BOM and fimware
    [BOM-final.xls, bom_final.ods, bom_final.xlsx]
